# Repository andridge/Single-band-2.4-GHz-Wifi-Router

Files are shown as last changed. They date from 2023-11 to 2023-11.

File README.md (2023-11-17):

# Single-band-2.4-GHz-Wifi-Router
It combines advanced 802.11 b/g/n standards for efficient data transfer, a robust power output, expandable memory, and a flexible USB port for enhanced functionality.


Specifications
Medium-Speed Connectivity: Achieve reliable wireless speeds of 130Mbps in real-world scenarios through 802.11 b/g/n standards (Wi-Fi 4).
Signal Strength: Maintain a strong wireless signal with a power output of 20dBm or 100mW for extended coverage.
Memory and Processing Power: Facilitate firmware upgrades and manage concurrent connections by offering expandable flash memory (from 4MB to 16MB) and RAM (from 32MB to 64MB) preferable to accommodate the firmware as well as multiple device connectivity..
Versatile Connectivity: Provide a USB 2.0 port for High-Speed devices and accommodate Full/Low-Speed devices through an external High-Speed hub.
User-Friendly Power Management: Enable operation via a micro-USB socket for convenient and accessible power supply options.
Radio Bands: Single-band (2.4 GHz).
Limitations
Limited to 802.11n, which restricts its maximum speed to 150 Mbps, suitable for basic to moderate wireless needs.
Operates in a single band (2.4 GHz), potentially leading to more crowded frequencies and interference in environments with many wireless devices.
Lack of MU-MIMO support restricts simultaneous data transmission to only one device at a time, impacting overall network efficiency in dense or multi-device environments.
Lacks an antenna although it's integratable.

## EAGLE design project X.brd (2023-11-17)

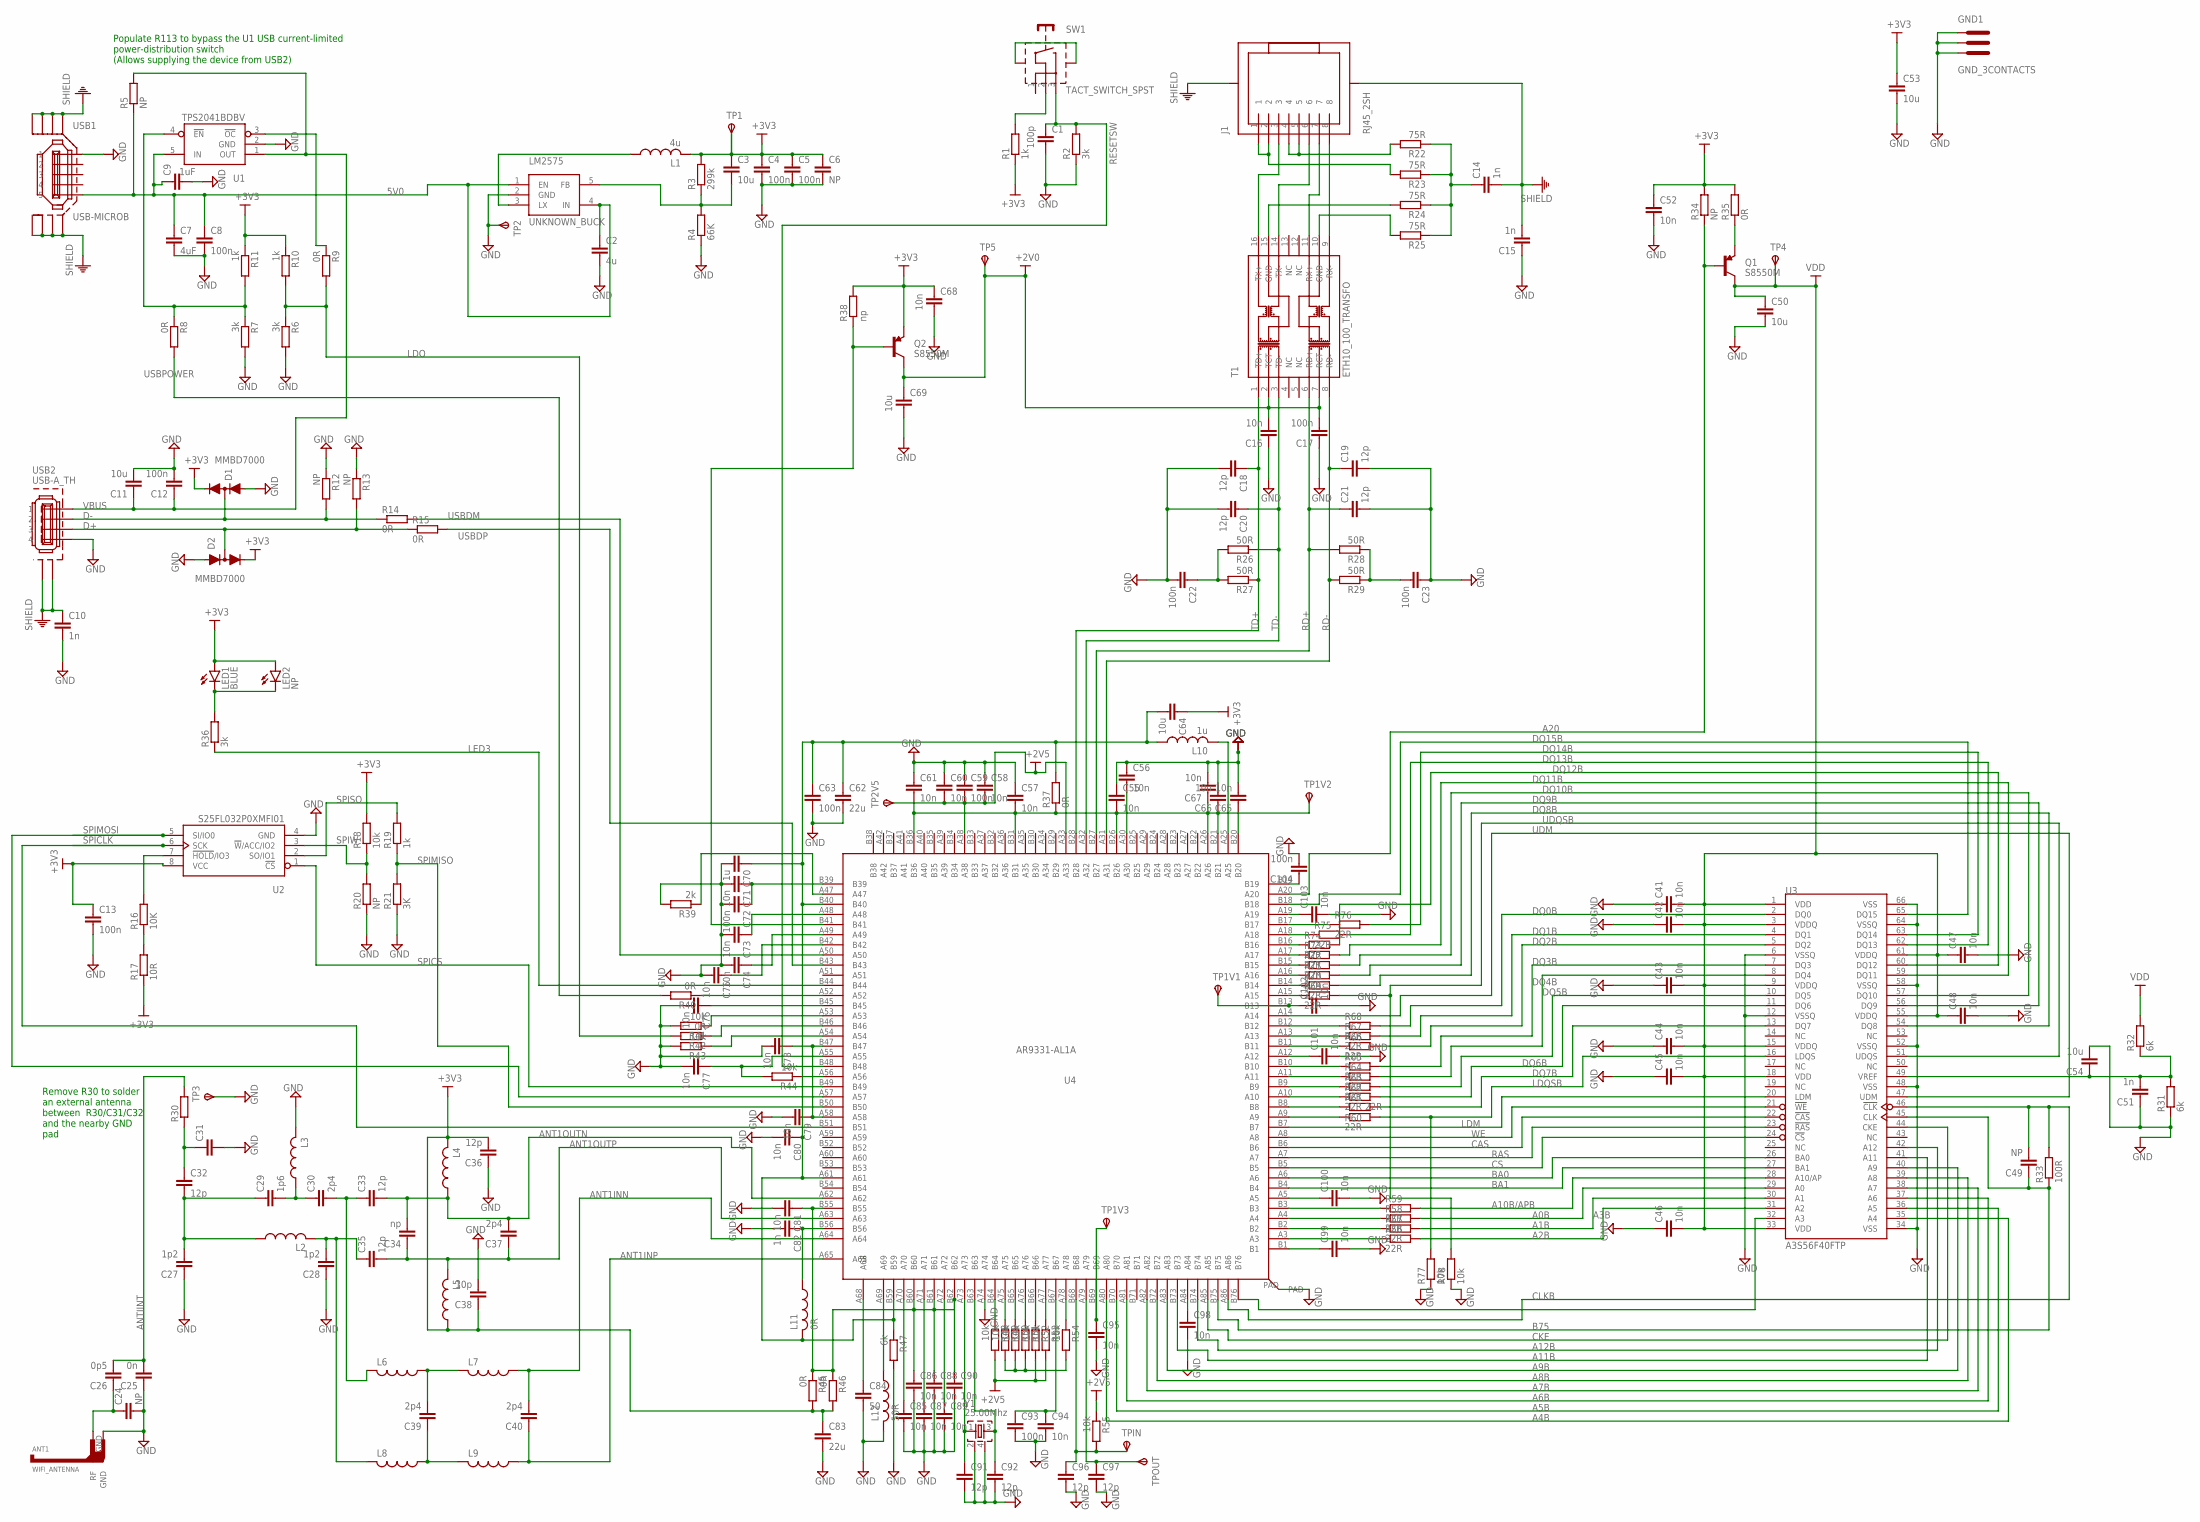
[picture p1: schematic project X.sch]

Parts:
ANT1: WIFI_ANTENNA
C1: 100p; C0402
C2: 4u; C0603
C3: 10u; C0603
C4, C5, C8, C13, C72, C93, C104: 100n; C0603
C6, C24, C49: NP; C0603
C7: 4uF; C0603
C9: 1uF; C0603
C10, C51, C82: 1n; C0603
C11, C50, C53, C54, C64: 10u; C0805
C12, C59, C63: 100n; C0805
C14, C15: 1n; C1206
C16: 10n; C1206
C17, C22, C23: 100n; C1206
C18, C19, C20, C21: 12p; C1206
C25: 0n; C0603
C26: 0p5; C0603
C27, C28: 1p2; C0603
C29: 1p6; C0603
C30, C37, C39, C40: 2p4; C0603
C31: CAP_0603; C0603
C32, C33, C35, C36, C91, C92, C96, C97: 12p; C0603
C34: np; C0603
C38: 10p; C0603
C41, C42, C43, C44, C45, C46, C47, C48, C52, C71, C73, C74, C75, C76, C77, C78, C79, C80, C81, C85, C86, C87, C88, C89, C90, C94, C95, C98, C99, C100, C101, C102, C103: 10n; C0603
C55, C56, C57, C58, C60, C61, C65, C66, C67: 10n; C0805
C62: 22u; C0805
C68: 10n; C0402
C69: 10u; C0402
C70: 1u; C0603
C83: 22u; C0603
C84: 50; C0603
D1, D2: MMBD7000; SOT23-3
GND1: GND_3CONTACTS; GND_3CONTACT
J1: RJ45_2SH; RJ45_LP_RA_SMT
L1: 4u; L0402
L2, L3, L4, L5, L6, L7, L8, L9: IND_0402; L0402
L10: 1u; L1008
L11: 0R; L0402
L12: 50R; L0402
LED1: BLUE; LED3MM
LED2: NP; LED3MM
LM2575: UNKNOWN_BUCK; SOT23-5
Q1, Q2: S8550M; SOT23-3
R1: 1k; R0402
R2: 3k; R0402
R3: 299k; R0603
R4: 66K; R0603
R5, R12, R13, R20, R34: NP; R0603
R6, R7, R36: 3k; R0603
R8, R9, R14, R15, R35, R37, R40, R42, R45, R46: 0R; R0603
R10, R11, R19: 1k; R0603
R16: 10K; R0603
R17: 10R; R0603
R18, R41, R43, R44, R48, R49, R50, R51, R52, R53, R54, R55, R77, R78: 10k; R0603
R21: 3K; R0603
R22, R23, R24, R25: 75R; R0402
R26, R27, R28, R29: 50R; R0402
R30: RES_0603; R0603
R31, R32, R47: 6k; R0603
R33: 100R; R0603
R38: np; R0603
R39: 2k; R0603
R56, R57, R58, R59, R60, R61, R62, R63, R64, R65, R66, R67, R68, R69, R70, R71, R72, R73, R74, R75, R76: 22R; R0603
SW1: TACT_SWITCH_SPST; TACT_SWITCH_SPST_RA_SMT
T1: ETH10_100_TRANSFO; H1601CG
TP1, TP1V1, TP1V2, TP1V3, TP2, TP2V5, TP3, TP4, TP5: TEST_PAD
TPIN: TEST_PAD
TPOUT: TEST_PAD
U1: TPS2041BDBV; SOT23-5
U2: S25FL032P0XMFI01; SOP8
U3: A3S56F40FTP; TSOP66
U4: AR9331-AL1A; DRMLF164
USB1: USB-MICROB
USB2: USB-A_TH
Y1: 25.00Mhz; CRYSTAL_32_25

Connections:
5V0: C2.1, C7.1, C8.1, C9.1, LM2575.1 (EN), LM2575.4 (IN), R5.1, U1.5 (IN), USB1.VBUS (5)
+2V0: C16.2, C17.2, C69.1, Q2.3 (C), T1.2 (TCT), T1.7 (RCT), TP5.1
+2V5: C58.2, C59.2, C60.2, R48.2, R52.2, R53.2, R55.1, TP2V5.1, U4.A33, U4.A38
+3V3: C3.1, C4.1, C5.1, C6.1, C13.1, C36.2, C38.1, C52.1, C53.1, C64.1, C68.1, C83.1, D1.2 (C), D2.2 (C), L1.2, L4.2, L5.1, LED1.A, LED2.A, Q2.2 (E), R1.1, R3.2, R10.1, R11.1, R17.1, R18.2, R34.2, R35.2, R38.2, R45.2, R46.2, TP1.1, U2.8 (VCC)
A0B: R58.2, U3.29 (A0)
A1B: R57.2, U3.30 (A1)
A2B: R56.2, U3.31 (A2)
A3B: U3.32 (A3), U4.B76
A4B: U3.35 (A4), U4.A80
A5B: U3.36 (A5), U4.B70
A6B: U3.37 (A6), U4.A81
A7B: U3.38 (A7), U4.A82
A8B: U3.39 (A8), U4.B72
A9B: U3.40 (A9), U4.A83
A10B/APB: R59.2, U3.28 (A10/AP)
A11B: U3.41 (A11), U4.B73
A12B: U3.42 (A12), U4.B74
A20: Q1.1 (B), R34.1, U4.A20
ANT1INN: C40.2, L7.1, U4.A64
ANT1INP: C40.1, L9.1, U4.A65
ANT1OUTN: C33.2, C34.2, C37.2, L4.1, U4.A62
ANT1OUTP: C34.1, C35.2, C37.1, L5.2, U4.A63
ANTIINT: C25.2, C26.2, R30.2
B75: C49.1, R33.1, U3.45 (CLK), U4.B75
BA0: U3.26 (BA0), U4.A6
BA1: U3.27 (BA1), U4.B4
CAS: U3.22 (!CAS), U4.B6
CKE: U3.44 (CKE), U4.A85
CLKB: C49.2, R33.2, U3.46 (!CLK), U4.A86
CS: U3.24 (!CS), U4.B5
D+: D2.3 (M), R13.2, R15.1, USB2.3
D-: D1.3 (M), R12.2, R14.1, USB2.2
DQ0B: R68.2, U3.2 (DQ0)
DQ1B: R67.2, U3.4 (DQ1)
DQ2B: R66.2, U3.5 (DQ2)
DQ3B: R65.2, U3.7 (DQ3)
DQ4B: R64.2, U3.8 (DQ4)
DQ5B: R63.2, U3.10 (DQ5)
DQ6B: R62.2, U3.11 (DQ6)
DQ7B: R61.2, U3.13 (DQ7)
DQ8B: R70.2, U3.54 (DQ8)
DQ9B: R71.2, U3.56 (DQ9)
DQ10B: R72.2, U3.57 (DQ10)
DQ11B: R73.2, U3.59 (DQ11)
DQ12B: R74.2, U3.60 (DQ12)
DQ13B: R75.2, U3.62 (DQ13)
DQ14B: R76.2, U3.63 (DQ14)
DQ15B: U3.65 (DQ15), U4.B18
GND: ANT1.GND, C1.2, C2.2, C4.2, C5.2, C6.2, C7.2, C8.2, C9.2, C10.2, C11.2, C12.2, C13.2, C15.1, C16.1, C17.1, C18.2, C19.2, C20.2, C21.2, C22.2, C23.1, C24.2, C25.1, C27.1, C28.1, C31.2, C36.1, C38.2, C41.1, C42.1, C43.1, C44.1, C45.1, C46.1, C47.2, C48.2, C50.2, C51.1, C52.2, C53.2, C54.2, C55.1, C56.1, C57.1, C58.1, C59.1, C60.1, C61.1, C62.2, C63.2, C65.2, C66.2, C67.2, C68.2, C69.2, C70.2, C71.2, C72.2, C73.2, C74.2, C75.2, C76.2, C77.2, C78.2, C79.2, C80.2, C81.2, C82.2, C83.2, C84.2, C85.2, C86.2, C87.2, C88.2, C89.2, C90.2, C91.2, C92.2, C93.2, C94.2, C95.2, C96.2, C97.2, C98.2, C99.2, C100.2, C101.2, C102.2, C103.2, C104.2, D1.1 (A), D2.1 (A), GND1.GND$1, GND1.GND$2, GND1.GND$3, L3.2, L12.2, LM2575.2 (GND), R2.1, R4.1, R6.2, R7.2, R12.1, R13.1, R20.1, R21.1, R31.1, R39.2, R41.2, R43.2, R47.2, R77.1, R78.1, TP2.1, TP3.1, U1.2 (GND), U2.4 (GND), U3.6 (VSSQ), U3.12 (VSSQ), U3.34 (VSS), U3.48 (VSS), U3.52 (VSSQ), U3.58 (VSSQ), U3.64 (VSSQ), U3.66 (VSS), U4.A74, U4.PAD, USB1.GND (1), USB2.4, Y1.2, Y1.4
LDM: U3.20 (LDM), U4.B7
LDO: R6.1, R9.2, R10.2, R42.2
LDQSB: R60.2, R77.2, U3.16 (LDQS)
LED3: R36.1, U4.B44
unnamed: C14.1, R22.1, R23.1, R24.1, R25.1
unnamed: R1.2, SW1.2
unnamed: SW1.S$1 (SH$1), SW1.S$2 (SH$2)
unnamed: C3.2, LM2575.5 (FB), R3.1, R4.2
unnamed: C71.1, C72.1, U4.B39
unnamed: Q2.1 (B), R38.1, U4.B41
unnamed: L1.1, LM2575.3 (LX)
unnamed: R7.1, R8.1, R11.2, U1.4 (!EN)
unnamed: C76.1, U4.B45
unnamed: R40.1, U4.A52
unnamed: R9.1, U1.3 (!OC)
unnamed: R16.1, R17.2
unnamed: R16.2, U2.7 (!HOLD!/IO3)
unnamed: J1.1, J1.2, R23.2
unnamed: J1.4, J1.5, R22.2
unnamed: J1.3, T1.16 (TX+)
unnamed: J1.6, T1.14 (TX-)
unnamed: R24.2, T1.15 (GND)
unnamed: J1.7, T1.11 (RX+)
unnamed: J1.8, T1.9 (RX-)
unnamed: R25.2, T1.10 (GND)
unnamed: R41.1, U4.A53
unnamed: R42.1, U4.B46
unnamed: C27.2, C29.1, C32.2, L2.1
unnamed: ANT1.RF, C24.1, C26.1
unnamed: C31.1, C32.1, R30.1
unnamed: C29.2, C30.1, L3.1
unnamed: C28.2, C35.1, L2.2, L8.2
unnamed: C22.1, R26.2, R27.2
unnamed: C30.2, C33.1, L6.2
unnamed: C23.2, R28.1, R29.1
unnamed: C51.2, C54.1, R31.2, R32.1, U3.49 (VREF)
unnamed: Q1.2 (E), R35.1
unnamed: C65.1, U4.B20
unnamed: C39.2, L6.1, L7.2
unnamed: C39.1, L8.1, L9.2
unnamed: R39.1, U4.A47
unnamed: LED1.K (C), LED2.K (C), R36.2
unnamed: C73.1, U4.A48
unnamed: C74.1, U4.A49
unnamed: C75.1, U4.B42
unnamed: C81.1, C86.1, C88.1, C90.1, R45.1, R46.1, U4.B55, U4.B60, U4.B61, U4.B62
unnamed: C56.2, U4.A30
unnamed: C55.2, C57.2, C61.2, C66.1, C67.1, R37.1, TP1V2.1, U4.A26, U4.B21, U4.B26, U4.B31, U4.B36
unnamed: C62.1, C63.1, C64.2, C70.1, C80.1, L10.1, L11.2, R37.2, R47.1, U4.A61, U4.B40, U4.B59
unnamed: R43.1, U4.A54
unnamed: C95.1, TP1V3.1, U4.B69
unnamed: C78.1, C79.1, U4.A58, U4.B47
unnamed: C82.1, L11.1, U4.B56
unnamed: C77.1, R44.2, U4.A55
unnamed: R44.1, U4.A56
unnamed: C91.1, U4.A73, Y1.1
unnamed: C84.1, U4.A68
unnamed: C92.1, U4.B63, Y1.3
unnamed: L12.1, U4.A69
unnamed: R49.2, R50.2, R51.2, R54.2
unnamed: C85.1, U4.A70
unnamed: R48.1, U4.B64
unnamed: C87.1, U4.A71
unnamed: R49.1, U4.A75
unnamed: C89.1, U4.A72
unnamed: R50.1, U4.B65
unnamed: R51.1, U4.A76
unnamed: R52.1, U4.B66
unnamed: R53.1, U4.A77
unnamed: R54.1, U4.A78
unnamed: C93.1, C94.1, U4.B67
unnamed: L10.2, U4.A25
unnamed: C96.1, R55.2, TPIN.1, U4.B68
unnamed: C97.1, TPOUT.1, U4.A79
unnamed: C98.1, U4.A84
unnamed: C99.1, U4.B1
unnamed: R56.1, U4.A3
unnamed: R57.1, U4.B2
unnamed: C100.1, U4.A5
unnamed: C101.1, U4.A12
unnamed: R66.1, U4.B11
unnamed: R61.1, U4.B8
unnamed: R62.1, U4.A10
unnamed: R63.1, U4.B9
unnamed: R64.1, U4.A11
unnamed: R65.1, U4.B10
unnamed: R59.1, U4.B3
unnamed: R58.1, U4.A4
unnamed: R60.1, U4.A9
unnamed: R67.1, U4.A13
unnamed: R68.1, U4.B12
unnamed: R69.1, U4.A15
unnamed: R70.1, U4.B14
unnamed: R71.1, U4.A16
unnamed: C102.1, TP1V1.1, U4.B13
unnamed: R73.1, U4.A17
unnamed: R72.1, U4.B15
unnamed: R74.1, U4.B16
unnamed: R75.1, U4.A18
unnamed: R76.1, U4.B17
unnamed: C103.1, U4.A19
unnamed: C104.1, U4.B19
RAS: U3.23 (!RAS), U4.A7
RD+: C21.1, R28.2, T1.6 (RD+), U4.B27
RD-: C19.1, R29.2, T1.8 (RD-), U4.A31
RESETSW: C1.1, R2.2, SW1.3, U4.B48
SHIELD: C10.1, C14.2, C15.2, J1.S$1 (SHIELD), J1.S$2 (SHIELD), USB1.P$1 (M0), USB1.P$2 (M7), USB1.S$1 (M1), USB1.S$2 (M2), USB1.S$3 (M3), USB1.S$4 (M4), USB1.S$5 (M5), USB1.S$6 (M6), USB2.S$1 (M1), USB2.S$2 (M2)
SPICLK: U2.6 (SCK), U4.B51
SPICS: U2.1 (!CS), U4.B49
SPIMISO: R19.1, R21.2, U4.B50
SPIMOSI: U2.5 (SI/IO0), U4.A57
SPISO: R19.2, U2.2 (SO/IO1)
SPIW: R18.1, R20.2, U2.3 (!W!/ACC/IO2)
TD+: C18.1, R27.1, T1.1 (TD+), U4.B28
TD-: C20.1, R26.1, T1.3 (TD-), U4.A32
UDM: U3.47 (UDM), U4.A14
UDQSB: R69.2, R78.2, U3.51 (UDQS)
USBDM: R14.2, U4.A50
USBDP: R15.2, U4.B43
USBPOWER: R8.2, R40.2
VBUS: C11.1, C12.1, R5.2, U1.1 (OUT), USB2.1
VDD: C41.2, C42.2, C43.2, C44.2, C45.2, C46.2, C47.1, C48.1, C50.1, Q1.3 (C), R32.2, TP4.1, U3.1 (VDD), U3.3 (VDDQ), U3.9 (VDDQ), U3.15 (VDDQ), U3.18 (VDD), U3.33 (VDD), U3.55 (VDDQ), U3.61 (VDDQ)
WE: U3.21 (!WE), U4.A8

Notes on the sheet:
Populate R113 to bypass the U1 USB current-limited power-distribution switch (Allows supplying the device from USB2)
Remove R30 to solder an external antenna between R30/C31/C32 and the nearby GND pad

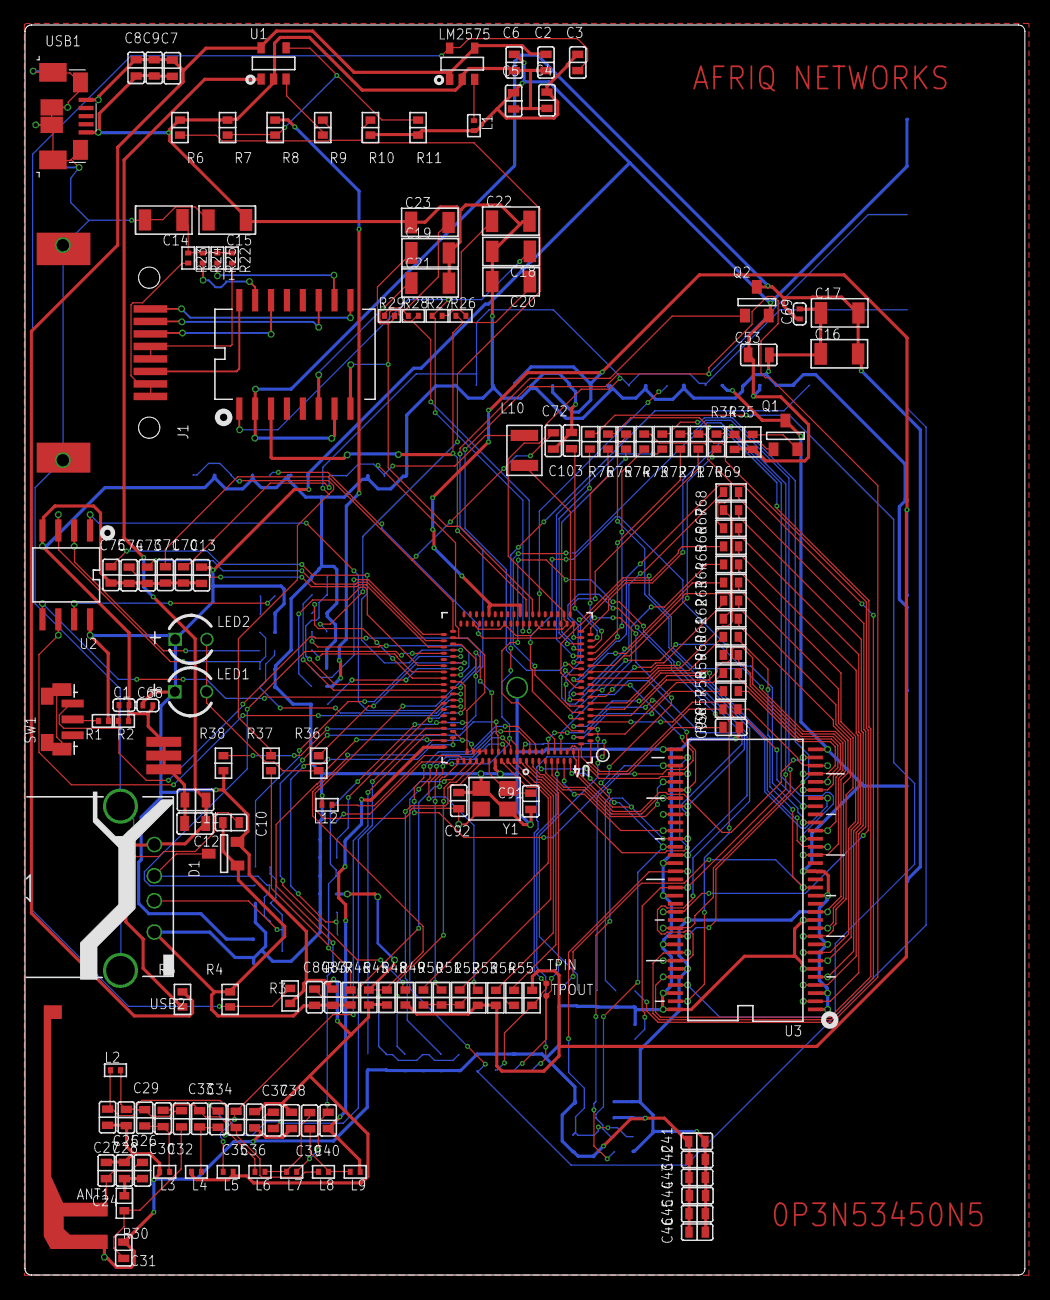
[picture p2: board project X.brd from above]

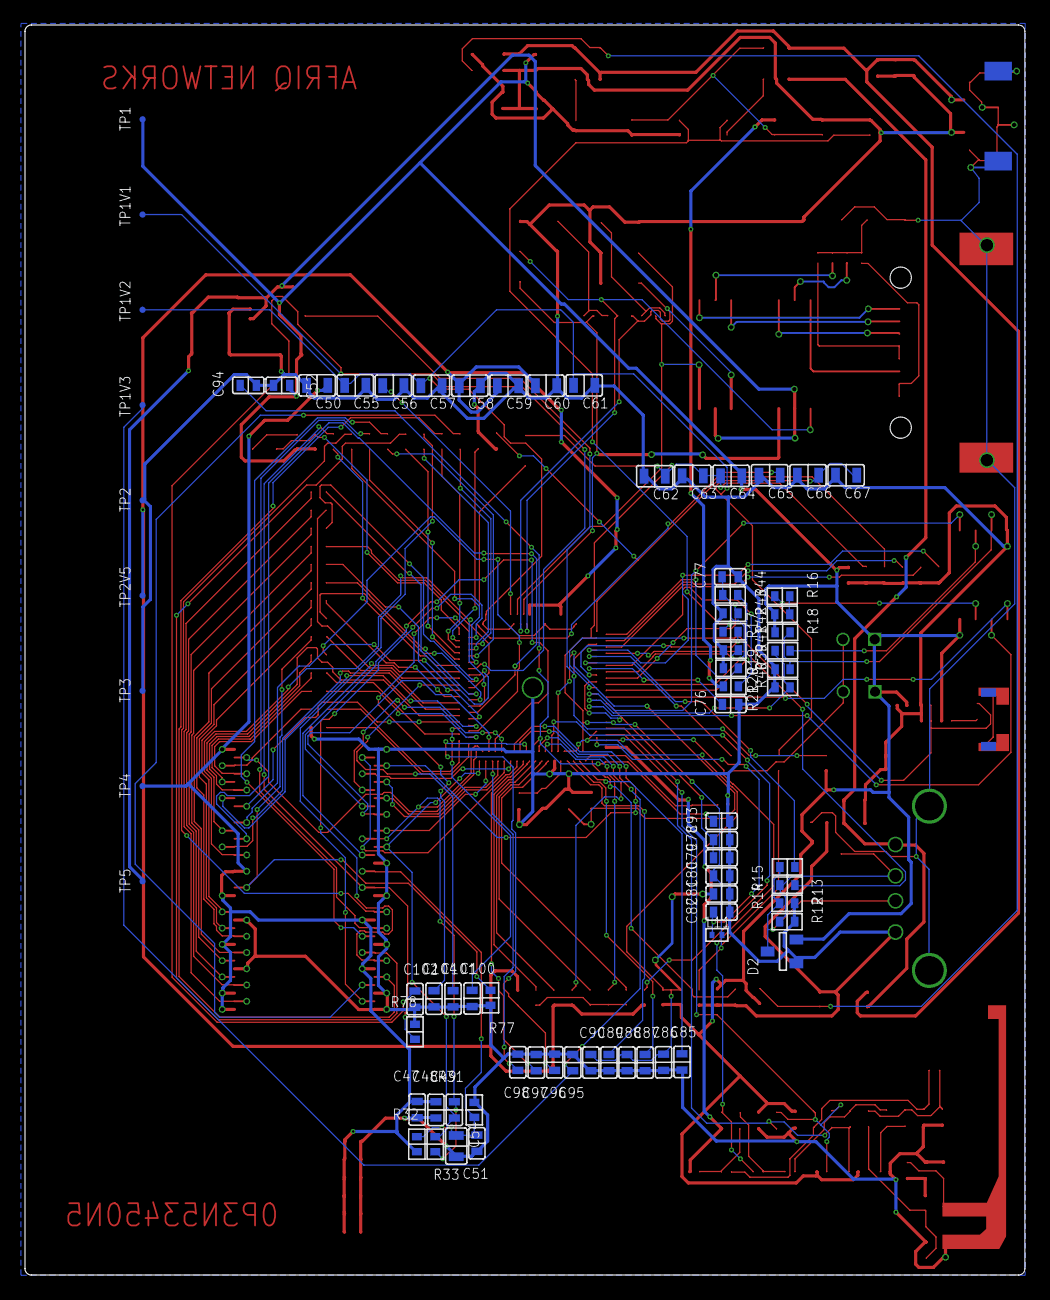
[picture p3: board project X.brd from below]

Board: 2 copper layers, 80.0 x 100.0 mm, 224 parts (75 on the bottom side), 172 nets.

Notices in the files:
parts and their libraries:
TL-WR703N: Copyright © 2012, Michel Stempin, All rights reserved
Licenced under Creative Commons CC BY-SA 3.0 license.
